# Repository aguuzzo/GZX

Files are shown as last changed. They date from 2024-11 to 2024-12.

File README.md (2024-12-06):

# **Robot Seguidor de Líneas**

Este proyecto implementa un robot seguidor de líneas basado en un Arduino Nano, 6 sensores CNY70, motores Pololu y un driver de motores. El robot utiliza un algoritmo de control para seguir de forma eficiente una línea negra sobre un fondo blanco.

---

## **Características**

- **Sensores:** 6 sensores CNY70 para detección precisa de la línea.  
- **Controlador:** Arduino Nano para procesamiento y control.  
- **Motores:** Motores Pololu de corriente continua para el movimiento.  
- **Driver de Motores:** Permite controlar la dirección y velocidad de los motores.  
- **Algoritmo de Control:** Basado en control proporcional (P) o proporcional-derivativo (PD) para seguir la línea.

---

## **Componentes**

- **Microcontrolador:** Arduino Nano (ATmega328P).  
- **Sensores:** 6 sensores ópticos CNY70.  
- **Motores:** Motores Pololu con caja reductora.  
- **Driver de Motores:** L298N o TB6612FNG.  
- **Fuente de Alimentación:** Batería de 7.4V (para los motores) y regulador de 5V para el Arduino y sensores.  
- **Estructura:** Chasis con diseño ligero y estable.  

---

## **Conexiones**

### **Sensores CNY70**  
Conectados a las entradas analógicas del Arduino:  
- **A0, A1, A2, A3, A4, A5.**  

### **Driver de Motores**  
Pines del Arduino conectados al driver:  
- **ENA:** Pin 9 (Control de velocidad motor izquierdo).  
- **IN1, IN2:** Pines 7 y 6 (Control dirección motor izquierdo).  
- **ENB:** Pin 10 (Control de velocidad motor derecho).  
- **IN3, IN4:** Pines 5 y 4 (Control dirección motor derecho).  

---

## **Algoritmo Implementado**

1. Leer los valores de los sensores (valores analógicos).  
2. Convertir los valores a binarios según un umbral.  
3. Calcular la posición de la línea en relación con el centro de los sensores.  
4. Determinar el error y ajustar la velocidad de los motores mediante un controlador proporcional (P).  
5. Enviar comandos al driver para mover los motores.

---

## **Prueba y ajustes**
1. Calibrar Sensores: Ajusta el umbral para detectar correctamente la línea.
2. Optimización del Controlador: Ajusta la constante proporcional Kp para evitar oscilaciones y mejorar la estabilidad.
3. Pruebas Dinámicas: Evalúa el rendimiento en distintas trayectorias (curvas, bifurcaciones, etc.).

## **Código**

### **Ejemplo: Controlador Proporcional**
```cpp
#include <Arduino.h>

// Pines de sensores
const int sensores[6] = {A0, A1, A2, A3, A4, A5};

// Pines del driver
const int ENA = 9; // Velocidad motor izquierdo
const int IN1 = 7;
const int IN2 = 6;
const int ENB = 10; // Velocidad motor derecho
const int IN3 = 5;
const int IN4 = 4;

int lecturaSensores[6];
int posicion = 0;
int error = 0;
int velocidadBase = 150;
float Kp = 10; // Constante proporcional

void setup() {
  for (int i = 0; i < 6; i++) pinMode(sensores[i], INPUT);
  pinMode(ENA, OUTPUT);
  pinMode(ENB, OUTPUT);
  pinMode(IN1, OUTPUT);
  pinMode(IN2, OUTPUT);
  pinMode(IN3, OUTPUT);
  pinMode(IN4, OUTPUT);
}

void loop() {
  // Leer sensores
  posicion = 0;
  for (int i = 0; i < 6; i++) {
    lecturaSensores[i] = analogRead(sensores[i]) > 500 ? 1 : 0; // Umbral 500
    posicion += lecturaSensores[i] * (i - 2); // Peso relativo de cada sensor
  }

  // Calcular error
  error = posicion;

  // Control proporcional
  int ajuste = Kp * error;

  // Calcular velocidades
  int velocidadIzquierda = velocidadBase - ajuste;
  int velocidadDerecha = velocidadBase + ajuste;

  // Controlar motores
  moverMotor(ENA, IN1, IN2, velocidadIzquierda);
  moverMotor(ENB, IN3, IN4, velocidadDerecha);
  delay(10);
}

void moverMotor(int enable, int in1, int in2, int velocidad) {
  if (velocidad > 0) {
    digitalWrite(in1, HIGH);
    digitalWrite(in2, LOW);
  } else {
    digitalWrite(in1, LOW);
    digitalWrite(in2, HIGH);
    velocidad = -velocidad;
  }
  analogWrite(enable, constrain(velocidad, 0, 255));
}

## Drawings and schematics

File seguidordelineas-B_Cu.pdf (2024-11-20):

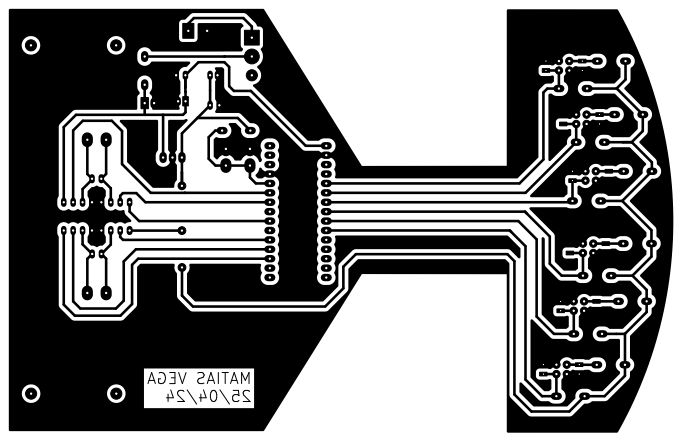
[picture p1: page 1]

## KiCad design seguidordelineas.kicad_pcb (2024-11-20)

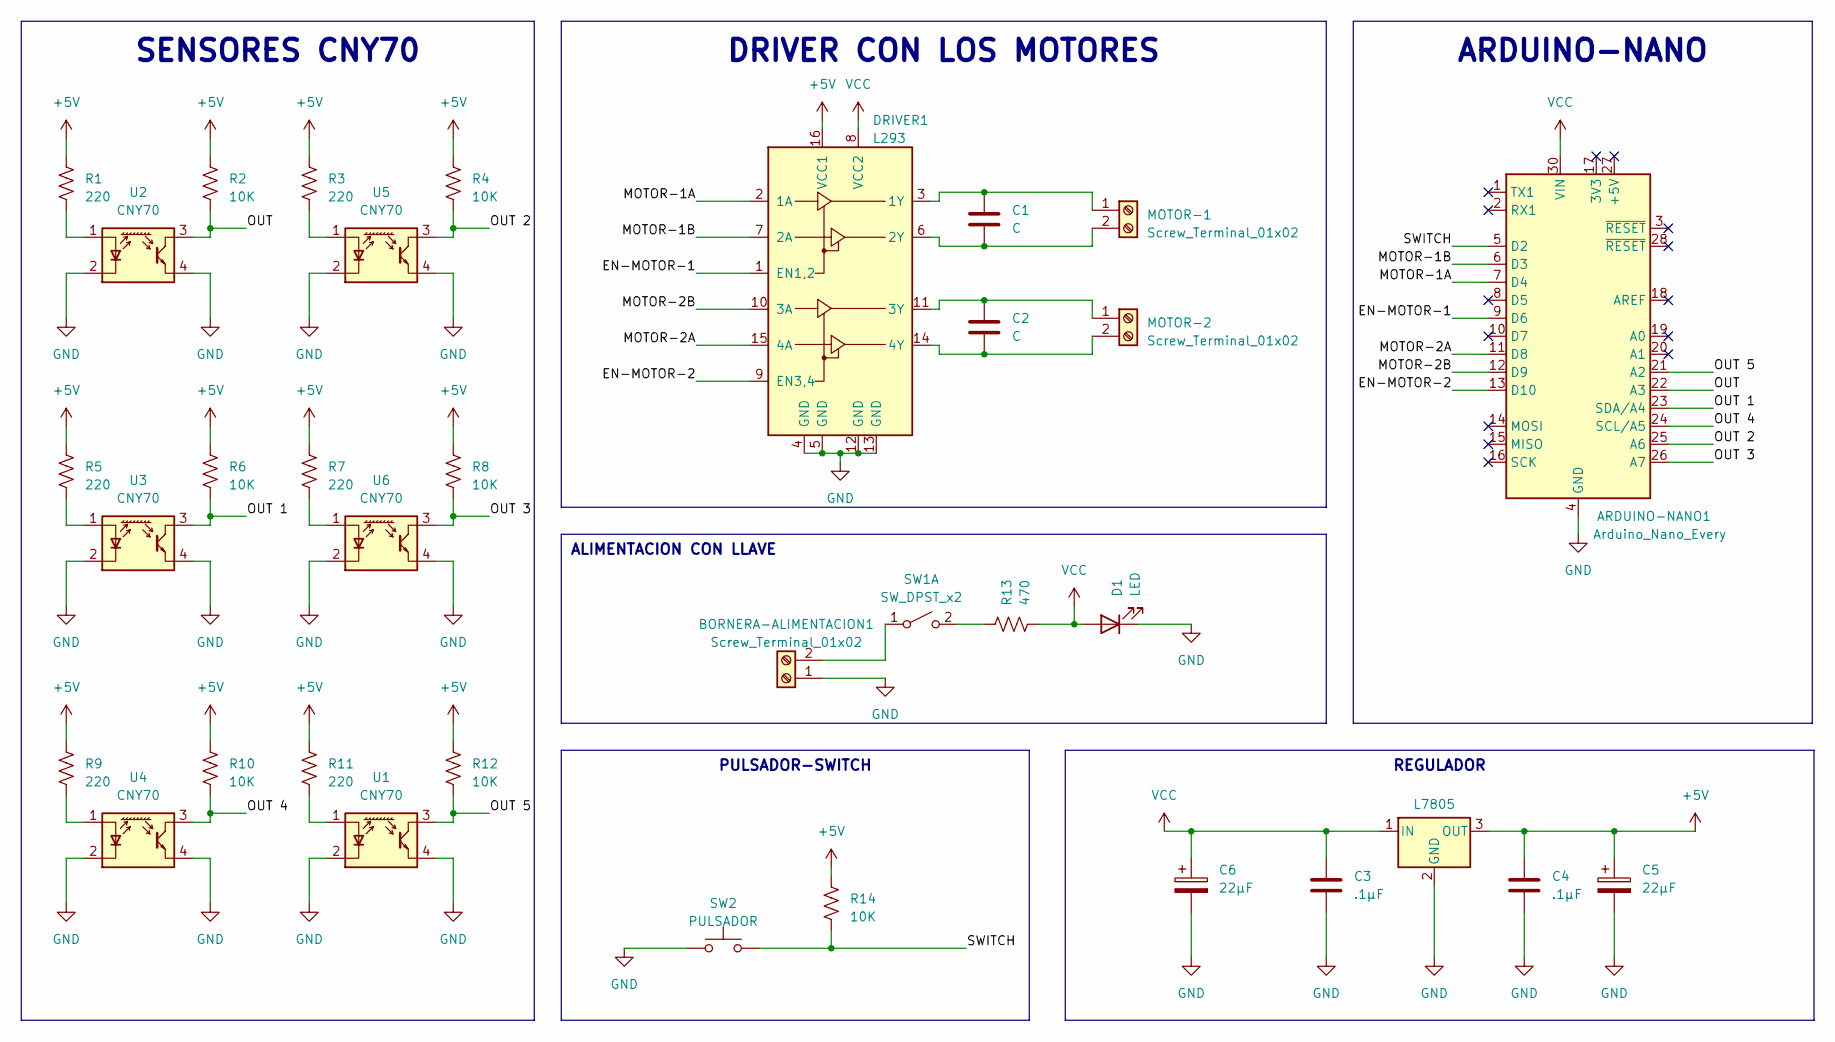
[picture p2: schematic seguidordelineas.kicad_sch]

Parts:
ARDUINO-NANO1: Arduino_Nano_Every; Arduino_Nano
BORNERA-ALIMENTACION1: Screw_Terminal_01x02; TerminalBlock_bornier-2_P5.08mm
C1, C2: C; CP_Radial_Tantal_D4.5mm_P2.50mm
C3, C4: .1μF; CP_Radial_Tantal_D4.5mm_P2.50mm
C5, C6: 22μF; CP_Radial_D5.0mm_P2.00mm
D1: LED; LED_D3.0mm_IRGrey
DRIVER1: L293; DIP-16_W7.62mm
MOTOR-1, MOTOR-2: Screw_Terminal_01x02; TerminalBlock_bornier-2_P5.08mm
R1, R3, R5, R7, R9, R11: 220; R_Axial_DIN0204_L3.6mm_D1.6mm_P7.62mm_Horizontal
R2, R4, R6, R8, R10, R12, R14: 10K; R_Axial_DIN0204_L3.6mm_D1.6mm_P7.62mm_Horizontal
R13: 470; R_Axial_DIN0204_L3.6mm_D1.6mm_P7.62mm_Horizontal
REGULADOR1: L7805; TO-220-3_Vertical
SW1: SW_DPST_x2; TerminalBlock_bornier-3_P5.08mm
SW2: PULSADOR; SW_PUSH_6mm_H4.3mm
U1, U2, U3, U4, U5, U6: CNY70; Vishay_CNY70

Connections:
+5V: C4.2, C5.1, DRIVER1.16 (VCC1), R1.1, R2.1, R3.1, R4.1, R5.1, R6.1, R7.1, R8.1, R9.1, R10.1, R11.1, R12.1, R14.1, REGULADOR1.3 (OUT)
/EN-MOTOR-1: ARDUINO-NANO1.9 (D6), DRIVER1.1 (EN1,2)
/EN-MOTOR-2: ARDUINO-NANO1.13 (D10), DRIVER1.9 (EN3,4)
/MOTOR-1A: ARDUINO-NANO1.7 (D4), DRIVER1.2 (1A)
/MOTOR-1B: ARDUINO-NANO1.6 (D3), DRIVER1.7 (2A)
/MOTOR-2A: ARDUINO-NANO1.11 (D8), DRIVER1.15 (4A)
/MOTOR-2B: ARDUINO-NANO1.12 (D9), DRIVER1.10 (3A)
/OUT: ARDUINO-NANO1.22 (A3), R2.2, U2.3 (C)
/OUT 1: ARDUINO-NANO1.23 (SDA/A4), R6.2, U3.3 (C)
/OUT 2: ARDUINO-NANO1.25 (A6), R4.2, U5.3 (C)
/OUT 3: ARDUINO-NANO1.26 (A7), R8.2, U6.3 (C)
/OUT 4: ARDUINO-NANO1.24 (SCL/A5), R10.2, U4.3 (C)
/OUT 5: ARDUINO-NANO1.21 (A2), R12.2, U1.3 (C)
/SWITCH: ARDUINO-NANO1.5 (D2), R14.2, SW2.2
GND: ARDUINO-NANO1.4 (GND), ARDUINO-NANO1.29 (GND), BORNERA-ALIMENTACION1.1, C3.2, C4.1, C5.2, C6.2, D1.1 (K), DRIVER1.4 (GND), DRIVER1.5 (GND), DRIVER1.12 (GND), DRIVER1.13 (GND), REGULADOR1.2 (GND), SW2.1, U1.2 (K), U1.4 (E), U2.2 (K), U2.4 (E), U3.2 (K), U3.4 (E), U4.2 (K), U4.4 (E), U5.2 (K), U5.4 (E), U6.2 (K), U6.4 (E)
unnamed: BORNERA-ALIMENTACION1.2, SW1.1 (A)
unnamed: C1.1, DRIVER1.3 (1Y), MOTOR-1.1
unnamed: C1.2, DRIVER1.6 (2Y), MOTOR-1.2
unnamed: C2.1, DRIVER1.11 (3Y), MOTOR-2.1
unnamed: C2.2, DRIVER1.14 (4Y), MOTOR-2.2
unnamed: R13.1, SW1.2 (B)
unnamed: R11.2, U1.1 (A)
unnamed: R1.2, U2.1 (A)
unnamed: R5.2, U3.1 (A)
unnamed: R9.2, U4.1 (A)
unnamed: R3.2, U5.1 (A)
unnamed: R7.2, U6.1 (A)
VCC: ARDUINO-NANO1.30 (VIN), C3.1, C6.1, D1.2 (A), DRIVER1.8 (VCC2), R13.2, REGULADOR1.1 (IN)

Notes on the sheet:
DRIVER CON LOS MOTORES
ALIMENTACION CON LLAVE
PULSADOR-SWITCH
REGULADOR
ARDUINO-NANO
SENSORES CNY70

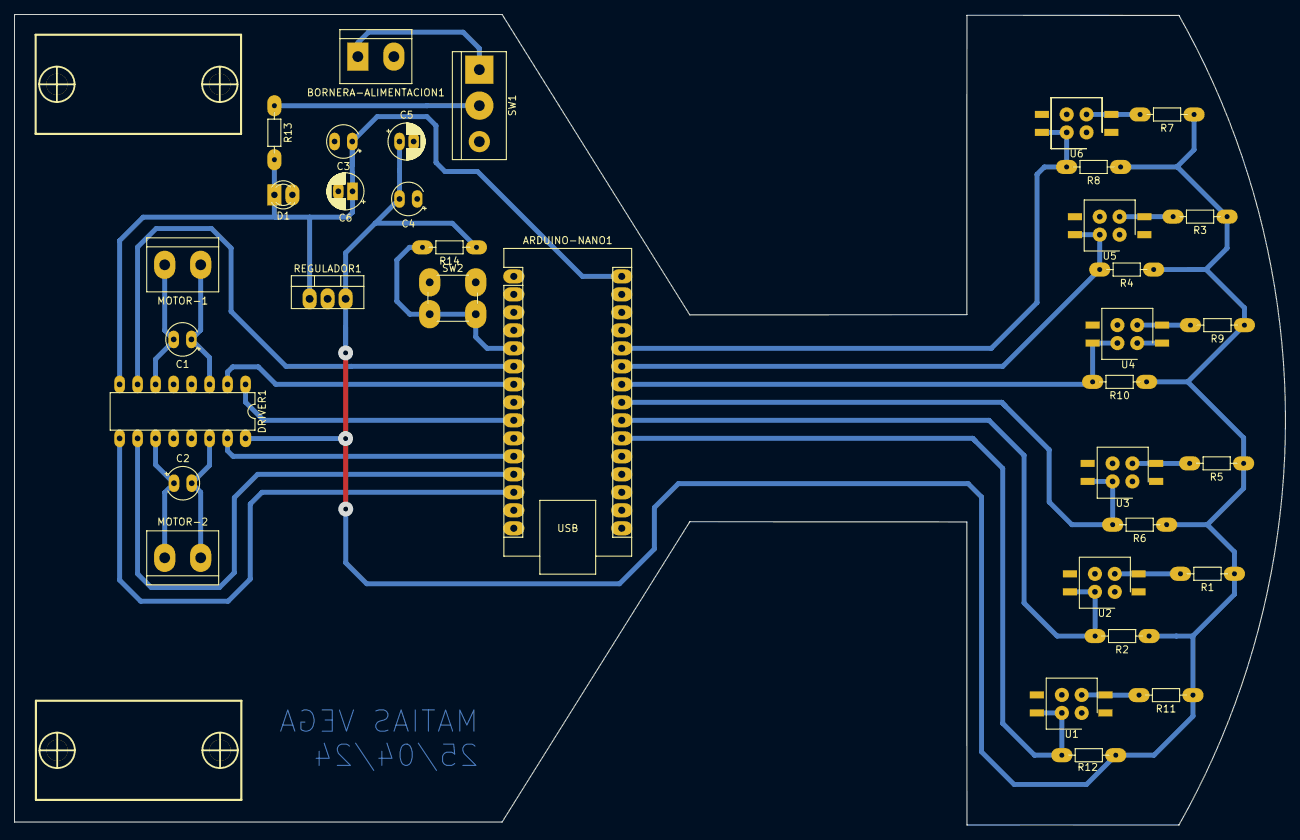
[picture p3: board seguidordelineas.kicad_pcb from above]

Board: 2 copper layers, 179.4 x 114.4 mm, 37 parts (0 on the bottom side), 28 nets.

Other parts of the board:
Pololu_Micro_Gear_Motor: VAL**; Pololu_Micro_Con_Soporte_Simple
Pololu_Micro_Gear_Motor#2: VAL**; Pololu_Micro_Con_Soporte_Simple
